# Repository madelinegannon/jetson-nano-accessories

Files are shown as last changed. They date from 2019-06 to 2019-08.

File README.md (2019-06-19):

### Jetson Nano Accessories
A variety of 3D printed mounts, adapters, and kits for NVIDIA's Jetson Nano.



## Overview

NVIDIA sent me a few of their new Jetson Nanos to play around and see what I might want to make. On first impression — the Nano is a solid Ubuntu computer, but I was really impressed with its portablity: if you look at their [Jetbot](https://github.com/NVIDIA-AI-IOT/jetbot) project, you can see that you can power the Nano plus a few motors with just a mobile phone charger. So that got me thinking about all the different — _and weird_ — places I could take a Nano ... and that led to me daydreaming about possible projects with this portable, powerful embedded computer.

To jumpstart my creativity, I decided to make a series of mounts, adapters, and kits for taking the Nano, a battery, and a camera into a bunch of different places. Some of them are pragmatic and useful — like the [Tripod Mount Kit](https://github.com/madelinegannon/jetson-nano-builds/blob/master/tripod-mount/). Others are a bit more odd and fun — like the [Utility Belt](https://github.com/madelinegannon/jetson-nano-builds/blob/master/utility-belt/) or [Gardening](https://github.com/madelinegannon/jetson-nano-builds/blob/master/gardening/) Kits.

I've included all the files to make and modify these 3D printable accessories in this repo. These kits let you attach the Nano to things like:
- Glass, with the [Suction Cup Kit](https://github.com/madelinegannon/jetson-nano-builds/blob/master/suction-cup-mount/)
- Metal, with the [Magnet Kit](https://github.com/madelinegannon/jetson-nano-builds/blob/master/magnetic-mount/)
- Tripods, with the [Tripod Kit](https://github.com/madelinegannon/jetson-nano-builds/blob/master/tripod-mount/)
- The Body, with the [Utility Belt Kit](https://github.com/madelinegannon/jetson-nano-builds/blob/master/utility-belt/)
- A Bike, with the [Bicycle Mount Kit](https://github.com/madelinegannon/jetson-nano-builds/blob/master/bicycle-mount/)
- The Ground, with the [Gardening Kit](https://github.com/madelinegannon/jetson-nano-builds/blob/master/gardening/)

| Suction Cup Kit | Magnet Kit | Tripod Kit | 
| :---: | :---: | :---: |
|  |   |  |

| Utility Belt | Bicycle Mount | Gardening Kit |
| :---: | :---: | :---: |
|  |  |  |

Plus I made a few stands for holding, displaying, or extending the Nano:

- [Nano Stand](https://github.com/madelinegannon/jetson-nano-builds/blob/master/stands/)
- [Nano Stand with Battery Clip](https://github.com/madelinegannon/jetson-nano-builds/blob/master/stands/)
- [Nano Stand with Battery Clip and Extruded Aluminium Extensions](https://github.com/madelinegannon/jetson-nano-builds/blob/master/stands/)

| Nano Stand | Nano Stand with Battery | Nano Stand with Battery and Extruded Aluminum |
| :---: | :---: | :---: |
|  |  |  | 

## Modular Clip System
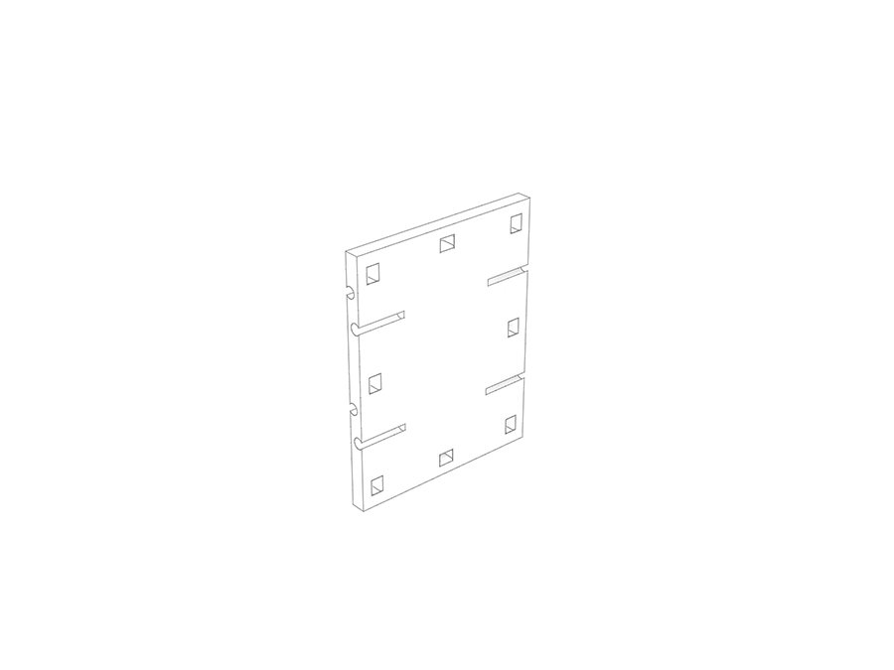
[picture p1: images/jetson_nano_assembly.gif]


My goal for these accessories was to have a kit of swapple, quick-to-print parts, so I could mix-and-match different clips, adapters, and mounts on the fly.

So, for example, over the course of my day, I could snap a Nano into the [Bicycle Mount Kit](https://github.com/madelinegannon/jetson-nano-builds/tree/master/bicycle-mount) for my commute to work, then snap it into a [Stand](https://github.com/madelinegannon/jetson-nano-builds/tree/master/stands) that's sitting on your workstation, and then maybe put my Nano on my [Refrigerator](https://github.com/madelinegannon/jetson-nano-builds/tree/master/magnetic-mount) or in my [Garden](https://github.com/madelinegannon/jetson-nano-builds/tree/master/garden-stake) when I got back home.  

### Components
The three basic components are a _Nano Clip_, that the Jetson Nano Developer Kit snaps into, a _Board Backer_, that protects the back of the Nano and has slots for the Nano and Battery Clips, and a _Battery Clip_, that a portable battery pack snaps into. Based on your scenario, you may or may need battery power — so there are other connection options for the rear slots in the Board Backer (e.g., [Suction Cups](https://github.com/madelinegannon/jetson-nano-builds/tree/master/suction-cup-mount)).

| Nano Clip | Board Backer | Battery Clip |
| :---: | :---: | :---: |
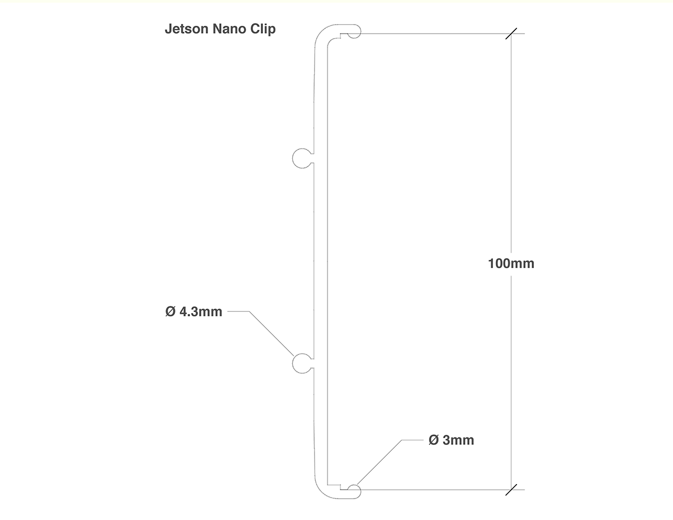
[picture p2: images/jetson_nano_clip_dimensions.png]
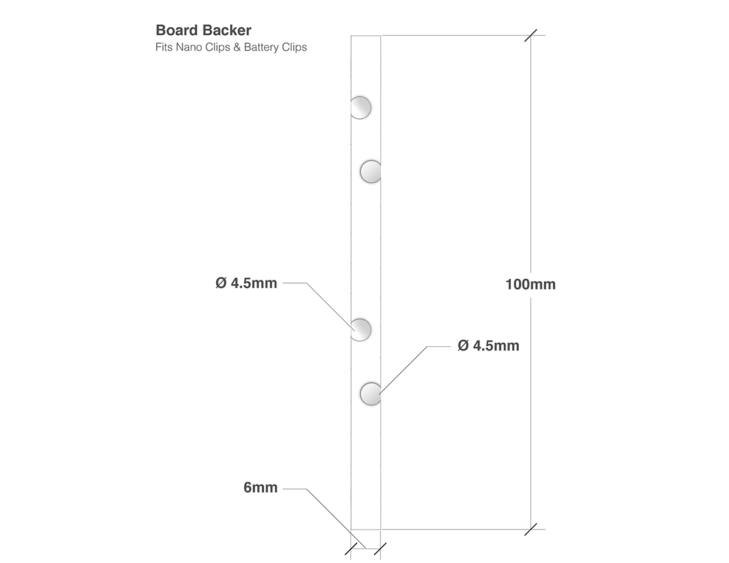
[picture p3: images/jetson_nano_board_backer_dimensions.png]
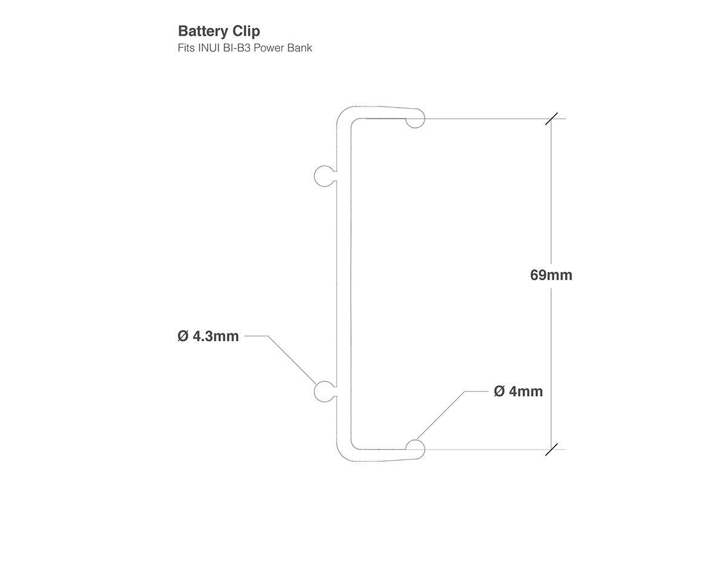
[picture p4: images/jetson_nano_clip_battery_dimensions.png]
|  |  |  |
| [jetson_nano_clip.stl](https://github.com/madelinegannon/jetson-nano-builds/blob/master/suction-cup-mount/jetson_nano_clip.stl) | [nano_board_backer.stl](https://github.com/madelinegannon/jetson-nano-builds/blob/master/suction-cup-mount/jetson_nano_board.stl) | [jetson_nano_clip_battery.stl](https://github.com/madelinegannon/jetson-nano-builds/blob/master/magnetic-mount/jetson_nano_clip_battery.stl) |

### Board Backer
The _Board Backer_ features slots for attaching the _Nano Clip_ and _Battery Clip_, as well as a series of holes for tip ties.

<p float="center">
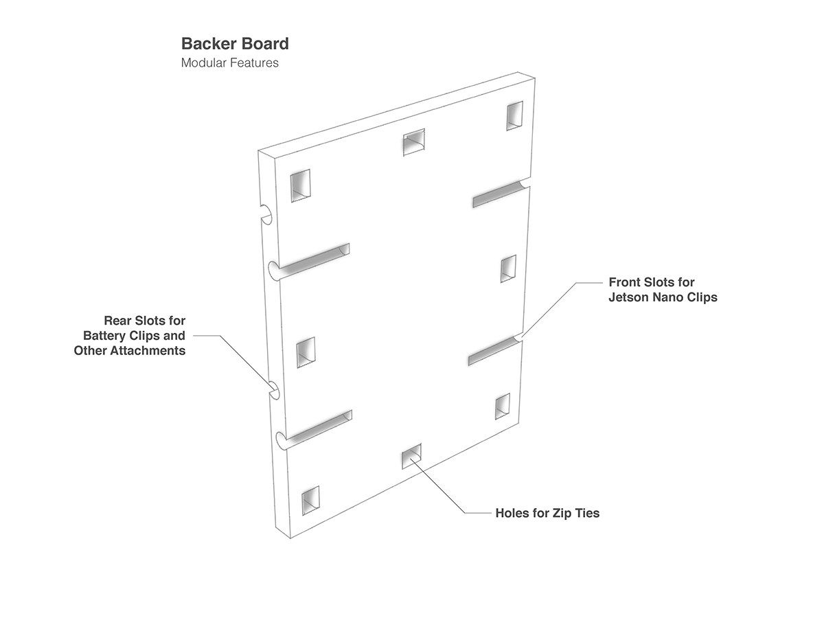
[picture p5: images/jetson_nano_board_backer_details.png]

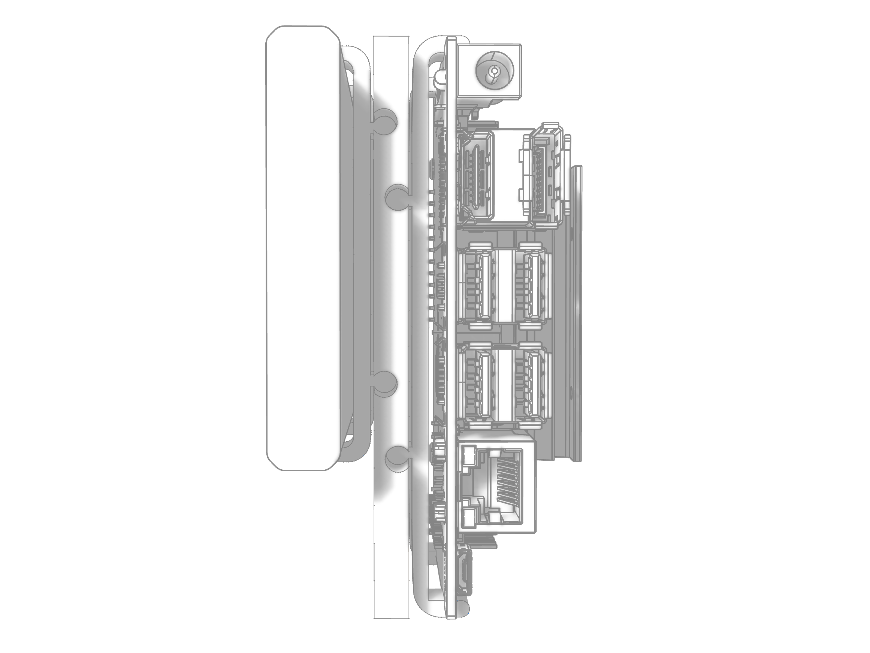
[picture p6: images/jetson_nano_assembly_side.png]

</p>

### Additional Clips
Here are a few more clips for the rear of the Board Backer that connect your Nano to different things:

| Bicycle Clips | Suction Cup Clips | Tripod Clips |
| :---: | :---: | :---: |
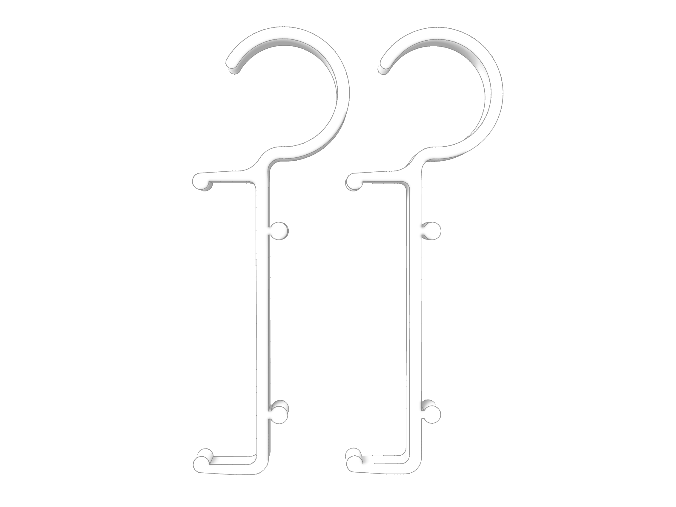
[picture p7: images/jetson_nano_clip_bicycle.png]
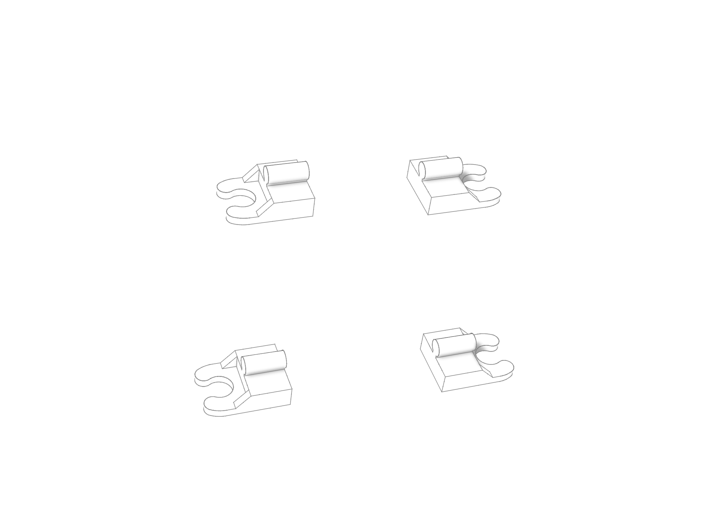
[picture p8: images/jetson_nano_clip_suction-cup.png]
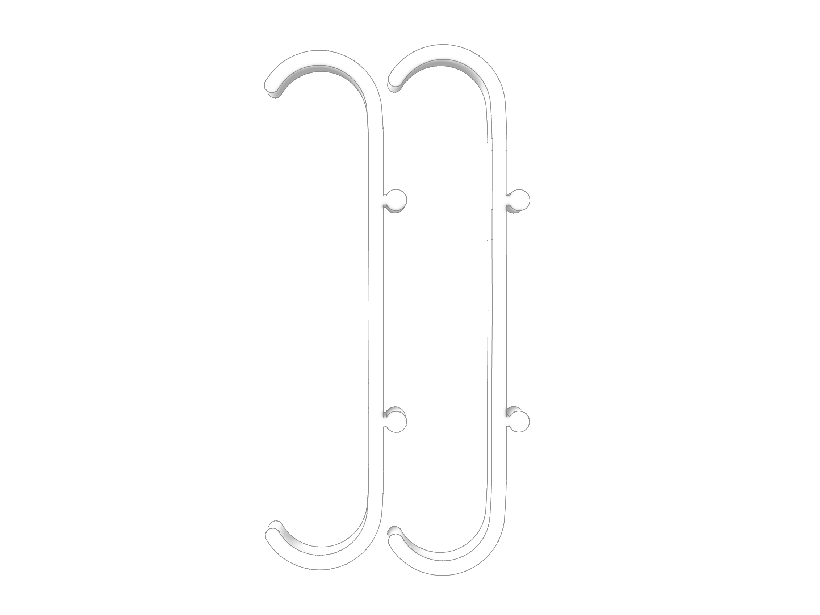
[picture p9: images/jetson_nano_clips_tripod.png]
|  |  |  |
| See the [Bicycle Mount Kit](https://github.com/madelinegannon/jetson-nano-builds/blob/master/bicycle-mount/) | See the [Suction Cup Kit](https://github.com/madelinegannon/jetson-nano-builds/blob/master/suction-cup-mount/) | See the [Tripod Mount Kit](https://github.com/madelinegannon/jetson-nano-builds/blob/master/tripod-mount/) |

### Stands
If you just want to show off your Nano in your workspace, I also made a few self-supporting stands that you can print.

| Jetson Nano Stand | Stand with Battery Clip | Stand with Battery Clip and Extruded Aluminium |
| :---: | :---: | :---: |
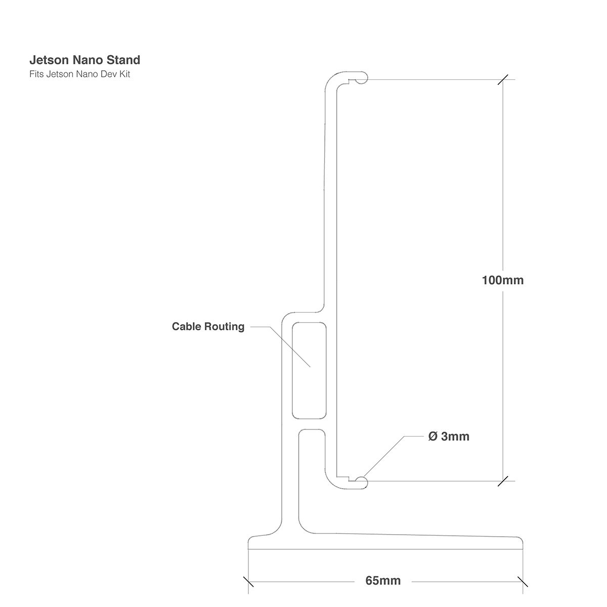
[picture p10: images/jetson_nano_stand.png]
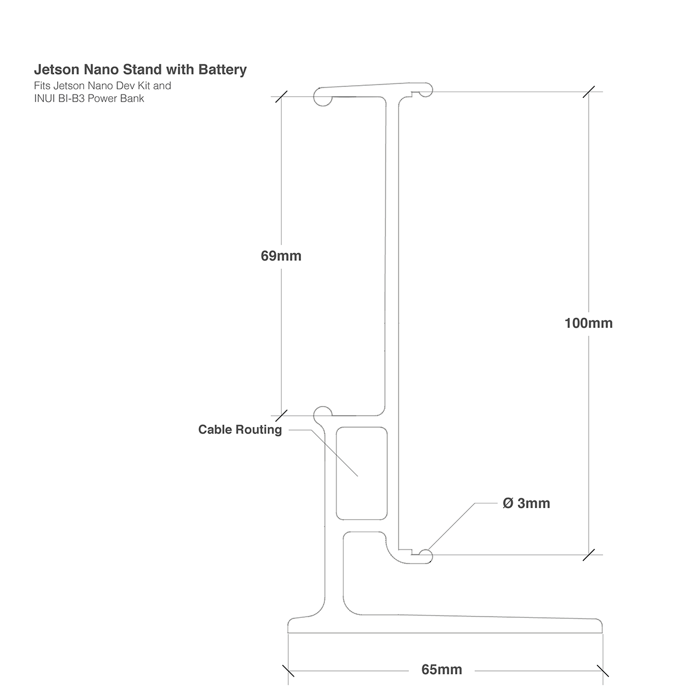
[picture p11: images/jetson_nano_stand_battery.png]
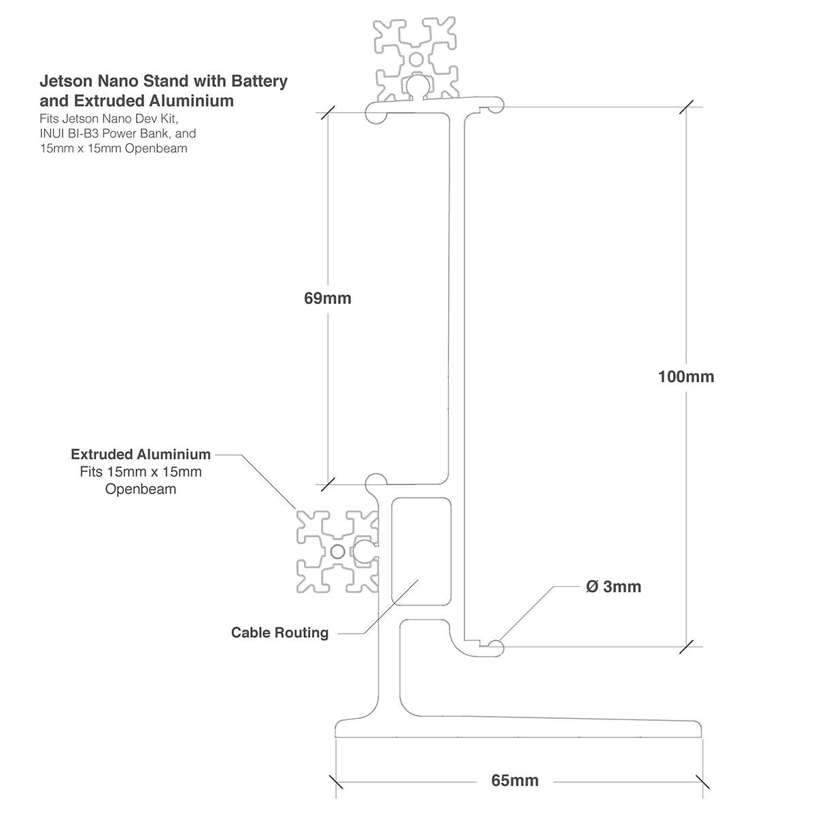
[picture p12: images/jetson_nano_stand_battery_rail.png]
|  |  |  |
| [jetson_nano_clip-feet.stl](https://github.com/madelinegannon/jetson-nano-builds/blob/master/stands/jetson_nano_clip-feet.stl) | [jetson_nano_clip-feet-battery.stl](https://github.com/madelinegannon/jetson-nano-builds/blob/master/stands/jetson_nano_clip-feet-battery.stl) | [jetson_nano_clip-feet-battery-rail.stl](https://github.com/madelinegannon/jetson-nano-builds/blob/master/stands/jetson_nano_clip-feet-battery-rail.stl) |

#### Build Settings
Each of included models were printed on a [Prusa i3 MK3S](https://www.prusa3d.com/original-prusa-i3-mk3/) printer. All my build settings are detail in the instructions for each assembly, but keep in mind that your settings and tolerances may vary based on the printer and printing method you use.

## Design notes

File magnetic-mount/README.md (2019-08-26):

### Jetson Nano Magnetic Mount

This Magnetic Mount Kit adds super-strong magnets to the back of your Jetson Nano, so you can stick it to metal surfaces that can be hard-to-reach or moving. 

|  Magnetic Mount (Overall) | Magnetic Mount (Detail) |
| :---: | :---: |
|  |  |

Here's a few project ideas to get started:
- Mount to your refrigerator, and use [real-time object detection](https://jkjung-avt.github.io/yolov3/) to keep track of groceries.
- Mount to your workbench, and use [real-time object detection](https://jkjung-avt.github.io/yolov3/) to keep track of where you put your tools.
- Mount to a structure, like an I-Beam, to detect who has been walking by.

> The neodymium magnets spec'ed here are quite strong, so be careful to not scratch the surface you're attaching to.

## Components

| Nano Clip | Battery Clip | Magnetic Board Backer | Magnet Clips |
| :---: | :---: | :---: | :---: |
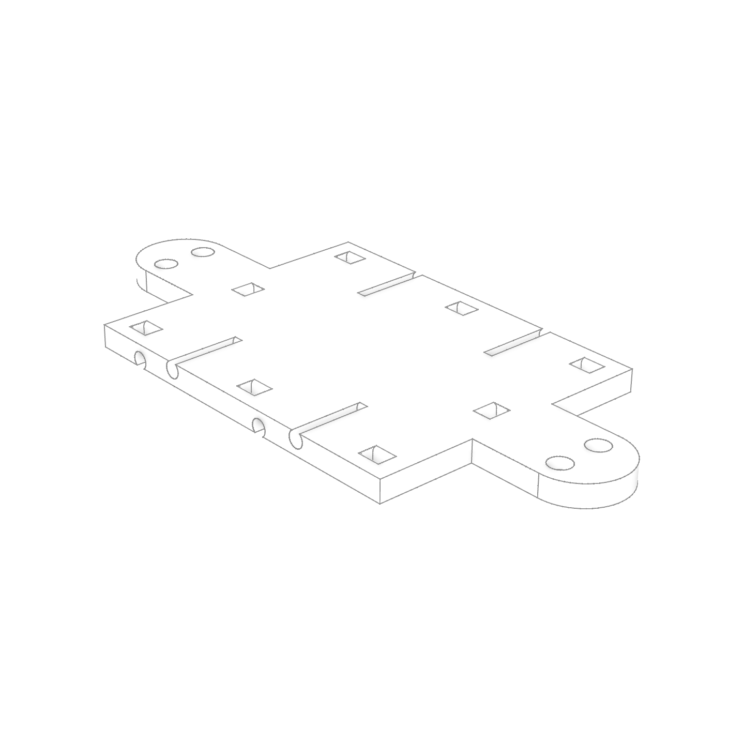
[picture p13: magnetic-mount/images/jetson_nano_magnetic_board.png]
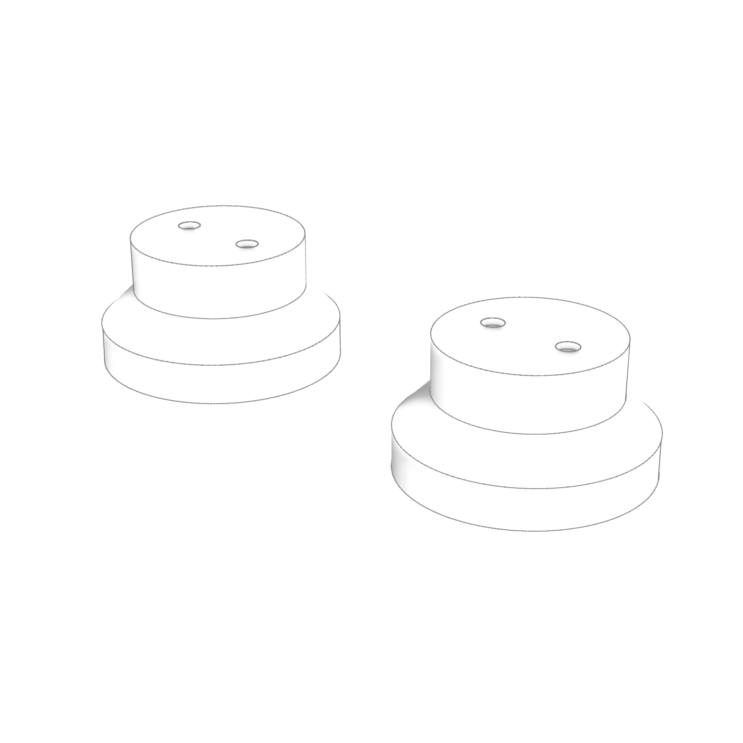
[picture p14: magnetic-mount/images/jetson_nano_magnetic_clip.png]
|  |  |  |  |

## Parts List

| Item | Qty | Reference  |
| --- |:---:| -----:|
| Magnetic Board Back | 1 | [jetson_nano_board_magnet.stl](https://github.com/madelinegannon/jetson-nano-builds/blob/master/magnetic-mount/jetson_nano_board_magnet.stl) |
| Magent Clip  | 2 | [jetson_nano_clip_magnet.stl](https://github.com/madelinegannon/jetson-nano-builds/blob/master/magnetic-mount/jetson_nano_clip_magnet.stl) |
| Nano Clip  | 2 | [jetson_nano_clip.stl](https://github.com/madelinegannon/jetson-nano-builds/blob/master/magnetic-mount/jetson_nano_clip.stl) |
| Battery Clip  | 2 | [jetson_nano_clip_battery.stl](https://github.com/madelinegannon/jetson-nano-builds/blob/master/magnetic-mount/jetson_nano_clip_battery.stl) |
| Neodymium Disc Magent | 2 | [32mm x 3mm Magnets](https://www.amazon.com/gp/product/B06XD2X45M/) |
| M3x8 screw | 2 | [Assorted Screw Set](https://www.amazon.com/VIGRUE-1080pcs-Assortment-Kit-Wrenches/dp/B07FCDL2SY/) |
| M3 nut | 2 | [Assorted Screw Set](https://www.amazon.com/VIGRUE-1080pcs-Assortment-Kit-Wrenches/dp/B07FCDL2SY/) |
| Portable Battery | 1 | [INUI Power Bank](https://www.amazon.com/INIU-Portable-External-Powerbank-Compatible/dp/B07H6LB4J4/) |

## Assembly Instructions

1. Print the [jetson_nano_board_magnet.stl](https://github.com/madelinegannon/jetson-nano-builds/blob/master/magnetic-mount/jetson_nano_board_magnet.stl),  two [jetson_nano_clip_magnet.stl](https://github.com/madelinegannon/jetson-nano-builds/blob/master/magnetic-mount/jetson_nano_clip_magnet.stl), two [jetson_nano_clip.stl](https://github.com/madelinegannon/jetson-nano-builds/blob/master/garden-stake/jetson_nano_clip.stl), and two [jetson_nano_clip_battery.stl](https://github.com/madelinegannon/jetson-nano-builds/blob/master/magnetic-mount/jetson_nano_clip_battery.stl) at 20% infill.
2. Attach the Magnet Clips to the printed boards.
    - Begin by pushing two M3 nuts into the hexagonal holes inside each of the Magent Clips.
    - Screw each of the Magent Clips to the back of the printed board using two M3x8 screws.
    - Push in a Disc Magent into the bottom of each Magnet Clip (this should be a tight fiction fit and snap into place).
        - The Magnet Clips _should_ hold each Disc Magnet in place with friction alone — add glue if the fit is too loose.
3. Slide the two Jetson Nano Clips into the front of the printed board (this should be a tight fiction fit). 
    - _Note: The front of the board has centered slots and a rougher finish._
4. Snap your Jetson Nano into the Clips — you should hear a nice click sound.
5. Slide the two Battery Clips into the back of the printed board (this should be a tight fiction fit). 
    - _Note: The back of the board has off-centered slots and a smoother finish._
6. Snap your Portable Battery into the Battery Clips, and plug in the Nano and other peripherals.
7. Stick onto a metal surface and go!

#### Printer Settings
Each of these parts were printed on a [Prusa i3 MK3S](https://www.prusa3d.com/original-prusa-i3-mk3/) printer using the MK3S_MK3_0.2_Fast profile (0.2mm layer height) with PLA. 

## Credits
1. The [Nano Clip](https://github.com/madelinegannon/jetson-nano-builds/blob/master/magnetic-mount/jetson_nano_clip.stl) and [Battery Clip](https://github.com/madelinegannon/jetson-nano-builds/blob/master/magnetic-mount/jetson_nano_clip_battery.stl) were derived from this [8020 Rail ATMega2560 Clip](https://www.thingiverse.com/thing:155130) by [the_digital_dentist](https://www.thingiverse.com/the_digital_dentist/about).

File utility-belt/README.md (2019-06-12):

### Jetson Nano Utility Belt
The Jetson Nano is lightweight and power-efficient, which means you can easily wear it on your body. This Utility Belt assembly places the Jetson Nano developer kit and a portable battery pack around your waist, so you can add cameras, sensors, and robots directly on your person.

|  Utility Belt (Overall) | Utility Belt (Detail) |
| :---: | :---: |
|  |  |

Here's a few project ideas to get started:
- Build your own DIY Head Mounted Device.
- Make robotic garments that respond to their environment.
- Create a "sixth sense" that lets to navigate the world in a new way.
- Make a sassy robotic parrot that lives on your shoulder.

> Keep in mind that the Nano's heat sink can get hot, and that the board can short if it comes into contact with metal (like from watches or bracelets). Consider adding a case around the top of the board if how you wear your is likely to come in contact with skin or metal. 

## Components

| Nano Clip | Belt Board Buckle | Belt Battery Buckle |
| :---: | :---: | :---: |
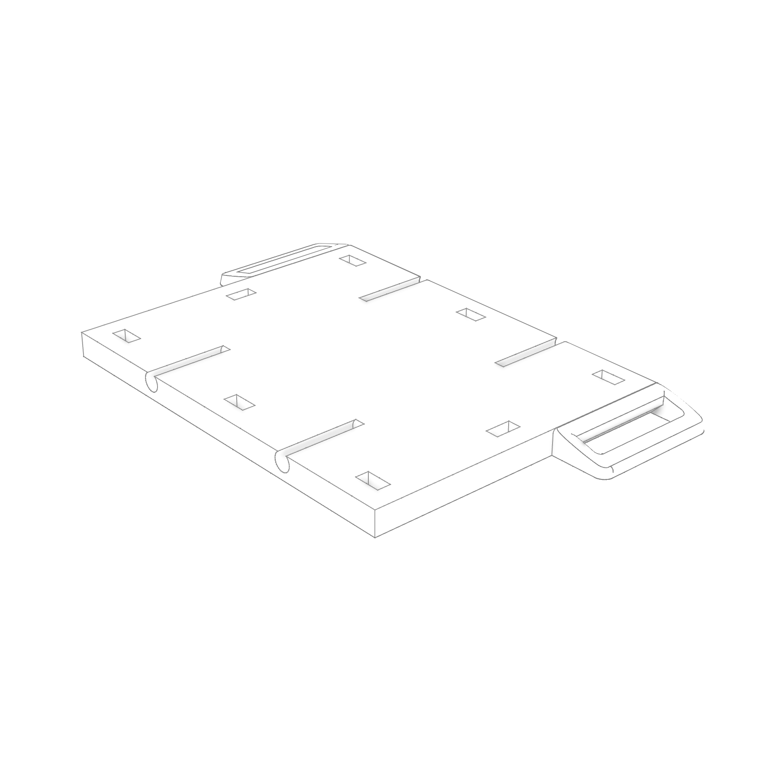
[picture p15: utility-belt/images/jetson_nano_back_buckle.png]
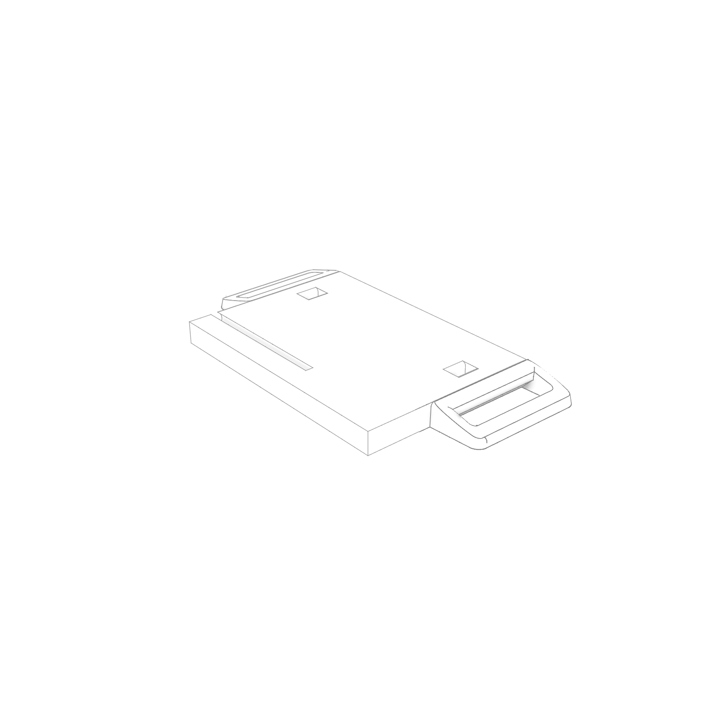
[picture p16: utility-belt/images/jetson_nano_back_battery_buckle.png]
|  |  |  | 

## Parts List

| Item | Qty | Reference  |
| --- |:---:| -----:|
| Nano Board Buckle | 1 | [jetson_nano_board_buckle.stl](https://github.com/madelinegannon/jetson-nano-builds/blob/master/utility-belt/jetson_nano_board_buckle.stl) |
| Battery Board Buckle | 1 | [jetson_nano_battery_buckle.stl](https://github.com/madelinegannon/jetson-nano-builds/blob/master/utility-belt/jetson_nano_battery_buckle.stl) |
| Nano Clip  | 2 | [jetson_nano_clip.stl](https://github.com/madelinegannon/jetson-nano-builds/blob/master/garden-utility/jetson_nano_clip.stl) |
| Battery Clip (Vertical) | 1 | [jetson_nano_clip_battery-vertical.stl](https://github.com/madelinegannon/jetson-nano-builds/blob/master/utility-belt/jetson_nano_clip_battery-vertical.stl) |
| Buckles, Glides, & Nylon Strap | — | [BTNOW 15 Piece Set](https://www.amazon.com/gp/product/B075ZTLKJC/) |
| Portable Battery | 1 | [INUI Power Bank](https://www.amazon.com/INIU-Portable-External-Powerbank-Compatible/dp/B07H6LB4J4/) |

## Assembly Instructions

1. Print the [jetson_nano_board_buckle.stl](https://github.com/madelinegannon/jetson-nano-builds/blob/master/utility-belt/jetson_nano_board_buckle.stl), [jetson_nano_battery_buckle.stl](https://github.com/madelinegannon/jetson-nano-builds/blob/master/utility-belt/jetson_nano_battery_buckle.stl), two [jetson_nano_clip.stl](https://github.com/madelinegannon/jetson-nano-builds/blob/master/garden-utility/jetson_nano_clip.stl), and one [jetson_nano_clip_battery-vertical.stl](https://github.com/madelinegannon/jetson-nano-builds/blob/master/utility-belt/jetson_nano_clip_battery-vertical.stl) at 20% infill.
2. Slide the two Jetson Nano Clips into the front of the printed board with buckle (this should be a tight fiction fit). 
    - _Note: This board has multiple slots for clips._
3. Snap your Jetson Nano into the Clips — you should hear a nice click sound.
4. Slide the one Battery Clip (Vertical) into the back of the printed battery board with buckle (this should be a tight fiction fit). 
    - _Note: The battery board only has one slot for a clip._
5. Snap your Portable Battery into the Battery Clip, and plug in the Nano and other peripherals.
6. Attach the plastic Buckle, Glides, and Nylon Straps following these instructions: [Steps 1-6](https://images-na.ssl-images-amazon.com/images/I/91%2BgqnHoY0L._SL1500_.jpg) and [Steps 7-10](https://images-na.ssl-images-amazon.com/images/I/81tcsMIyBYL._SL1500_.jpg).
7. Adjust the Nano and Portable Battery so that the weight is balanced.
8. Buckle up and go.

#### Printer Settings
Each of these parts were printed on a [Prusa i3 MK3S](https://www.prusa3d.com/original-prusa-i3-mk3/) printer using the MK3S_MK3_0.2_Fast profile (0.2mm layer height) with PLA. 

## Credits
1. The [Nano Clip](https://github.com/madelinegannon/jetson-nano-builds/blob/master/garden-utility/jetson_nano_clip.stl) and [Battery Clip](https://github.com/madelinegannon/jetson-nano-builds/blob/master/garden-utility/jetson_nano_clip_battery-vertical.stl) were derived from this [8020 Rail ATMega2560 Clip](https://www.thingiverse.com/thing:155130) by [the_digital_dentist](https://www.thingiverse.com/the_digital_dentist/about).

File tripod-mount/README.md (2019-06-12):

### Jetson Nano Tripod Mount
This Jetson Nano Tripod Mount lets you attach the Jetson Nano developer kit to any leg of a [Manfrotto 028B Tripod](https://www.manfrotto.us/black-triman-camera-tripod). Attaching the Nano to the tripod leg keeps the tripod head clear for cameras and other sensors, while keeping the computer close and mobile. This design takes advantage of the 028B's tapered, twin shanked leg — so you can easily snap on the printed tripod clips, and slide the assembly up the leg until you have a snug connection.

|  Tripod Mount (Overall) | Tripod Mount (Detail) |
| :---: | :---: |
|  |  |

## Components

| Nano Clip | Board Backer | Tripod Clips |
| :---: | :---: | :---: |
|  |  |  |

## Parts List

| Item | Qty | Reference  |
| --- |:---:| -----:|
| Board Back | 1 | [jetson_nano_board.stl](https://github.com/madelinegannon/jetson-nano-builds/blob/master/tripod-mount/jetson_nano_board.stl) |
| Nano Clip  | 2 | [jetson_nano_clip.stl](https://github.com/madelinegannon/jetson-nano-builds/blob/master/tripod-mount/jetson_nano_clip.stl) |
| Nano Tripod Clips | 1 | [jetson_nano_clips_tripod.stl](https://github.com/madelinegannon/jetson-nano-builds/blob/master/tripod-mount/jetson_nano_clips_tripod.stl) |

## Assembly Instructions

1. Print the [jetson_nano_board.stl](https://github.com/madelinegannon/jetson-nano-builds/blob/master/tripod-mount/jetson_nano_board.stl),  [jetson_nano_clips_tripod.stl](https://github.com/madelinegannon/jetson-nano-builds/blob/master/tripod-mount/jetson_nano_clips_tripod.stl), and two [jetson_nano_clip.stl](https://github.com/madelinegannon/jetson-nano-builds/blob/master/garden-utility/jetson_nano_clip.stl) at 20% infill.
2. Slide the two Jetson Nano Clips into the front of the printed board (this should be a tight fiction fit). 
    - _Note: The front of the board has centered slots and a rougher finish._
3. Snap your Jetson Nano into the Clips — you should hear a nice click sound.
4. Slide the two Tripod Clips into the back of the printed board (this should be a tight fiction fit). 
    - The two Tripod Clips are slightly different widths to account for the taper of the tripod leg.
        - The wider clip goes in the top slot on the back of the board.
        - The narrower clip goes in the bottom slot on the back of the board.
    -  _Note: The back of the board has off-centered slots and a smoother finish._
5. Once the tripod clips are attached, position the clips over the middle of the leg, and then slide the assembly up the leg until you feel a snug fit. This should be around 2"- 3" from the top of the leg.
6. Plug in power, sensors and peripherals, and get going.

#### Printer Settings
Each of these parts were printed on a [Prusa i3 MK3S](https://www.prusa3d.com/original-prusa-i3-mk3/) printer using the MK3S_MK3_0.2_Fast profile (0.2mm layer height) with PLA. 

## Credits
1. The [Nano Clip](https://github.com/madelinegannon/jetson-nano-builds/blob/master/garden-utility/jetson_nano_clip.stl) was derived from this [8020 Rail ATMega2560 Clip](https://www.thingiverse.com/thing:155130) by [the_digital_dentist](https://www.thingiverse.com/the_digital_dentist/about).

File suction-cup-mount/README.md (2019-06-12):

### Jetson Nano Suction Cup Mount
This Suction Cup Mount Kit adds suction cups to the back of your Jetson Nano, so you can stick it in hard-to-reach or moving surfaces. The suction cups work best on clean, smooth surfaces, such as glass or acrylic.

|  Suction Cup Mount (Overall) | Suction Cup Mount (Detail) |
| :---: | :---: |
|  |  |

Here's a few project ideas to get started:
- Mount inside your car, and use the Nano to create a DIY head's up display
- Mount to a window, and use the Nano as a motion detector
- Mount to a dry-erase board, and use the Nano for real-time sketch recognition

## Components

| Nano Clip | Board Backer | Suction Cup Clips |
| :---: | :---: | :---: |
|  |  |  |
| [jetson_nano_clip.stl](https://github.com/madelinegannon/jetson-nano-builds/blob/master/suction-cup-mount/jetson_nano_clip.stl) | [nano_board_backer.stl](https://github.com/madelinegannon/jetson-nano-builds/blob/master/suction-cup-mount/jetson_nano_board.stl) | [jetson_nano_clips_suction-cup.stl](https://github.com/madelinegannon/jetson-nano-builds/blob/master/suction-cup-mount/jetson_nano_clip_suction-cup.stl) |

## Parts List

| Item | Qty | Reference  |
| --- |:---:| -----:|
| Board Back | 1 | [jetson_nano_board.stl](https://github.com/madelinegannon/jetson-nano-builds/blob/master/suction-cup-mount/jetson_nano_board.stl) |
| Nano Clip  | 2 | [jetson_nano_clip.stl](https://github.com/madelinegannon/jetson-nano-builds/blob/master/suction-cup-mount/jetson_nano_clip.stl) |
| Suction Cup Clip | 4 | [jetson_nano_clips_suction-cup.stl](https://github.com/madelinegannon/jetson-nano-builds/blob/master/suction-cup-mount/jetson_nano_clip_suction-cup.stl) |
| 30mm Suction Cups | 4 | [Assorted Suction Cups](https://www.amazon.com/gp/product/B07H6CTWL4/) |

## Assembly Instructions

1. Print the [jetson_nano_board.stl](https://github.com/madelinegannon/jetson-nano-builds/blob/master/suction-cup-mount/jetson_nano_board.stl), two [jetson_nano_clip.stl](https://github.com/madelinegannon/jetson-nano-builds/blob/master/suction-cup-mount/jetson_nano_clip.stl), and four [jetson_nano_clips_tripod.stl]([jetson_nano_clips_suction-cup.stl](https://github.com/madelinegannon/jetson-nano-builds/blob/master/suction-cup-mount/jetson_nano_clip_suction-cup.stl) at 20% infill.
2. Slide the two Jetson Nano Clips into the front of the printed board (this should be a tight fiction fit). 
    - _Note: The front of the board has centered slots and a rougher finish._
3. Snap your Jetson Nano into the Clips — you should hear a nice click sound.
4. Slide a 30mm suction cup into each of the Suction Cup Clips (this should be a tight fiction fit). 
5. Slide each of the Suction Cup Clips into the back of the printed board (this should be a tight fiction fit). 
    - _Note: The back of the board has off-centered slots and a smoother finish._
6. Thoroughly clean the surface you'll be suctioning to, and then give the assembly a good press down onto the surface.
   - These suction cups work best on completely smooth surfaces, such as glass. 
7. Stick it and go!

#### Printer Settings
Each of these parts were printed on a [Prusa i3 MK3S](https://www.prusa3d.com/original-prusa-i3-mk3/) printer using the MK3S_MK3_0.2_Fast profile (0.2mm layer height) with PLA. 

## Credits
1. The [Nano Clip](https://github.com/madelinegannon/jetson-nano-builds/blob/master/garden-utility/jetson_nano_clip.stl) was derived from this [8020 Rail ATMega2560 Clip](https://www.thingiverse.com/thing:155130) by [the_digital_dentist](https://www.thingiverse.com/the_digital_dentist/about).

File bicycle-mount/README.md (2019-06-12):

### Jetson Nano Bicycle Mount
The Jetson Nano is lightweight and power-efficient, which means you can easily take it on the go. This Bicycle Mount assembly allows you to hang a Jetson Nano Developer Kit and Portable Battery from the horizontal crossbar of your bike. It also lets you attach sensors, cameras, or projectors to your handlebars using a standard 1/4-20 screw. Combine the two, and you'll have a number of ways to creatively enhance your daily commute.

|  Bicycle Mount (Overall) | Bicycle Mount (Detail) |
| :---: | :---: |
|  |  |

Here's a few project ideas to get started:
- Detect potholes and other hazards at night using an IR camera.
- Change the colors of LED lights on your bike based on proximity.
- Create a 3D map of your commute using a depth camera, like the [ZED](https://www.stereolabs.com/zed/) _(shown above)_.
- Attach a pico projector to add dynamic visuals to your night ride.

> The Jetson Nano is not waterproof, so use on a sunny day :)

## Components

| Nano Clip | Board Back | Bicycle Clips | Sensor Clip |
| :---: | :---: | :---: | :---: |
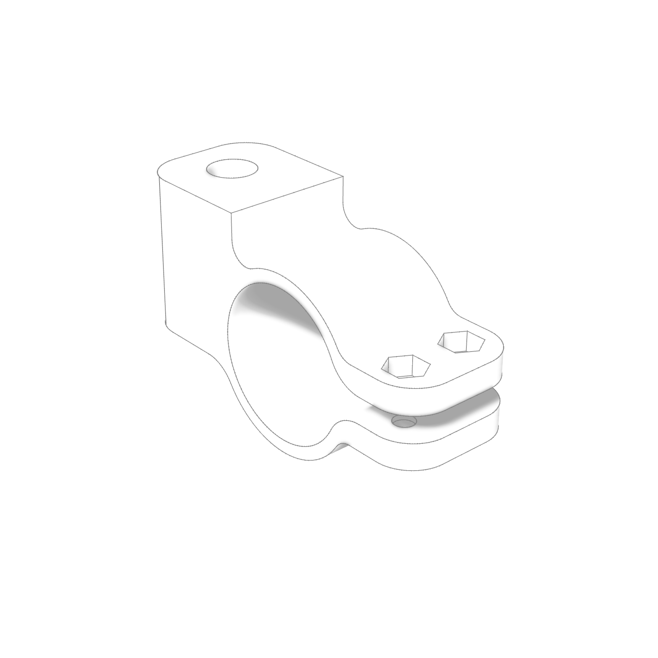
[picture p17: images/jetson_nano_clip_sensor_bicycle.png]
|  |  |  |  |

## Parts List

| Item | Qty | Reference  |
| --- |:---:| -----:|
| Board Back | 1 | [jetson_nano_board.stl](https://github.com/madelinegannon/jetson-nano-builds/blob/master/bicycle-mount/jetson_nano_board.stl) |
| Nano Clip  | 2 | [jetson_nano_clip.stl](https://github.com/madelinegannon/jetson-nano-builds/blob/master/bicycle-mount/jetson_nano_clip.stl) |
| Bicycle Clip | 2 | [jetson_nano_clip_bicycle.stl](https://github.com/madelinegannon/jetson-nano-builds/blob/master/bicycle-mount/jetson_nano_clip_bicycle.stl) |
| Bicycle Sensor Clip | 1 | [jetson_nano_clip_bicycle_sensor.stl](https://github.com/madelinegannon/jetson-nano-builds/blob/master/bicycle-mount/jetson_nano_clip_bicycle_sensor.stl) |
| M3x8 screw | 2 | [Assorted Screw Set](https://www.amazon.com/VIGRUE-1080pcs-Assortment-Kit-Wrenches/dp/B07FCDL2SY/) |
| M3 nut | 2 | [Assorted Screw Set](https://www.amazon.com/VIGRUE-1080pcs-Assortment-Kit-Wrenches/dp/B07FCDL2SY/) |
| 1/4-20 x 1" screw | 1 | [1/4-20 Screw Assortment](https://www.amazon.com/iExcell-4-20UNC-Stainless-Internal-Drives/dp/B07C9MWCSP/) |
| Portable Battery | 1 | [INUI Power Bank](https://www.amazon.com/INIU-Portable-External-Powerbank-Compatible/dp/B07H6LB4J4/) |

## Assembly Instructions

1. Print the [jetson_nano_board.stl](https://github.com/madelinegannon/jetson-nano-builds/blob/master/tripod-mount/jetson_nano_board.stl), two [jetson_nano_clip.stl](https://github.com/madelinegannon/jetson-nano-builds/blob/master/garden-utility/jetson_nano_clip.stl), and two [jetson_nano_clip_bicycle.stl](https://github.com/madelinegannon/jetson-nano-builds/blob/master/car-mount/jetson_nano_bicycle.stl) at 20% infill. Print one [jetson_nano_clip_bicycle_sensor.stl](https://github.com/madelinegannon/jetson-nano-builds/blob/master/car-mount/jetson_nano_bicycle_sensor.stl) at 10% infill.
2. Slide the two Jetson Nano Clips into the front of the printed board (this should be a tight fiction fit). 
    - _Note: The front of the board has centered slots and a rougher finish._
3. Snap your Jetson Nano into the Clips — you should hear a nice click sound.
4. Slide each of the Bicylce Clips into the back of the printed board (this should be a tight fiction fit). 
    - _Note: The back of the board has off-centered slots and a smoother finish._
5. Snap your Portable Battery into the back of the Bicycle Clips, and plug in the Nano and other peripherals.
6. Use the hooks of the bicycle clips to hang the whole assembly from the horizontal crossbar of your bike.
    - The hooks were designed for a 1" diameter crossbar.
    - If you find your Nano assembly is sliding forwards and backwards, add a zip tie before the first clip and after the last clip on your crossbar — these zip ties will act as stoppers. 
7. Snap the bicycle Sensor Clip around a handlebar of your bike.
    - Push the clip around the handlebar, with the hexagonal holes facing up and towards the bike seat. It should take some force to it on; but once on, the clip should be slightly loose around the handle bars.
    - The intrerior diameter of the Sensor Clip is just under 1" (23mm). However, the clips will fit larger diameter handlebars — you'll just need longer M3 screws.
8. Push two M3 nuts into the hexagonal holes on the Sensor Clip (these should be a tight fiction fit).
9. Screw two M3x8 screws from the bottom of the clip, through the M3 nuts. Tighten the two screws until the clip no longer slides or rotates.
10. Use the 1/4-20 x 1" screw to attach any number of sensors, cameras, or projectors to your handlebars.
11. Start pedalling and go!

#### Printer Settings
Each of these parts were printed on a [Prusa i3 MK3S](https://www.prusa3d.com/original-prusa-i3-mk3/) printer using the MK3S_MK3_0.2_Fast profile (0.2mm layer height) with PLA. 

## Credits
1. The [Nano Clip](https://github.com/madelinegannon/jetson-nano-builds/blob/master/garden-utility/jetson_nano_clip.stl) was derived from this [8020 Rail ATMega2560 Clip](https://www.thingiverse.com/thing:155130) by [the_digital_dentist](https://www.thingiverse.com/the_digital_dentist/about).

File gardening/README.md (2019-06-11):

### Jetson Nano Garden Stake
The Jetson Nano is lightweight and power-efficient, which means you can easily take it outdoors. This Garden Stake assembly has a place to clip in a Jetson Nano developer kit and a portable battery pack, as well as cameras and other peripherals. The pointy stake is great for holding the Nano in soft ground.

Here's a few project ideas to get started:
- Detect and report on bugs and pests in your garden.
- Detect poorly irrigated parts of your lawn.
- Take it to the beach to monitor your sun exposure.
- Use it to drive your outdoor projection mapping projects.

> The Jetson Nano is not waterproof, so use on a sunny day :)



## Components

| Nano Clip | Battery Clip | Outdoor Board Back | Stake |
| :---: | :---: | :---: | :---: |
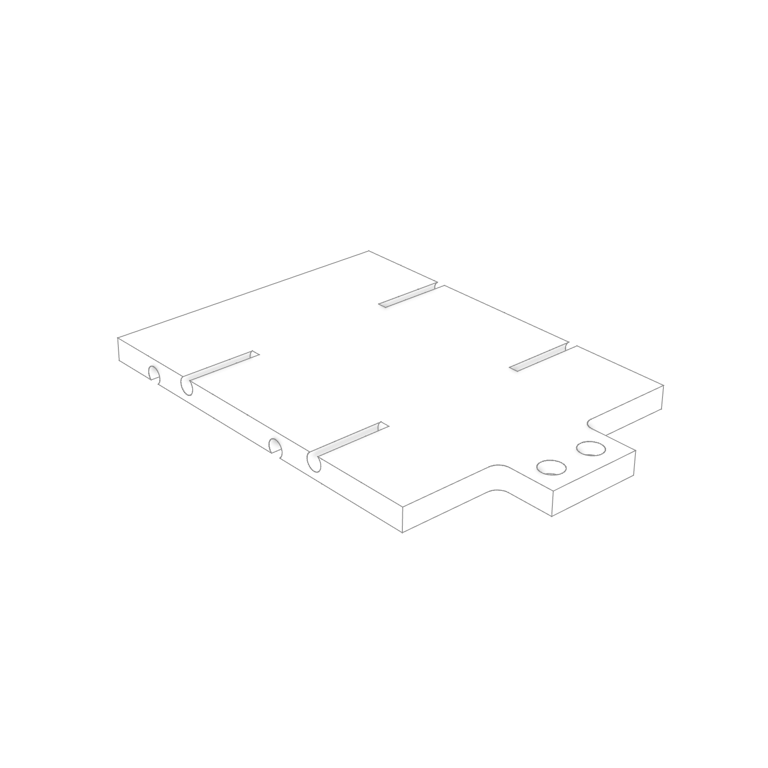
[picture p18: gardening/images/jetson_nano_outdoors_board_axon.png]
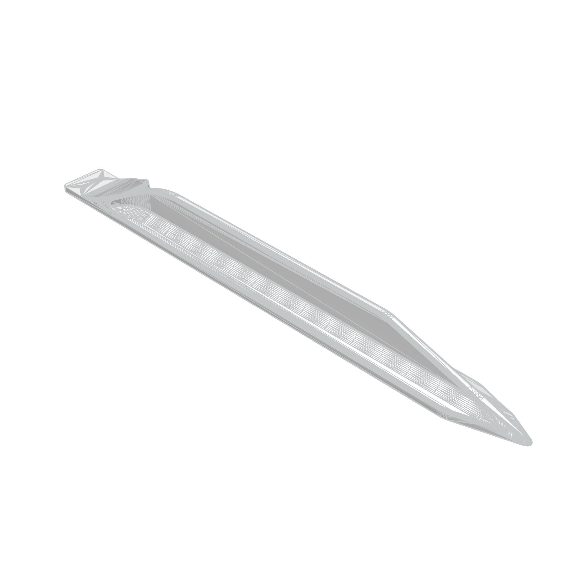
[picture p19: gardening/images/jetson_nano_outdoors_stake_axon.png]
|  |  |  |  |

## Parts List

| Item | Qty | Reference  |
| --- |:---:| -----:|
| Stake | 1 | [jetson_nano_outdoors_stake.stl](https://github.com/madelinegannon/jetson-nano-builds/blob/master/gardening/jetson_nano_outdoors_stake.stl) |
| Board Back | 1 | [jetson_nano_outdoors_stake_board.stl](https://github.com/madelinegannon/jetson-nano-builds/blob/master/gardening/jetson_nano_outdoors_stake_board.stl) |
| Nano Clip  | 2 | [jetson_nano_clip.stl](https://github.com/madelinegannon/jetson-nano-builds/blob/master/gardening/jetson_nano_clip.stl) |
| Battery Clip  | 2 | [jetson_nano_clip_battery.stl](https://github.com/madelinegannon/jetson-nano-builds/blob/master/gardening/jetson_nano_clip_battery.stl) |
| M3x12 screw | 2 | [Assorted Screw Set](https://www.amazon.com/VIGRUE-1080pcs-Assortment-Kit-Wrenches/dp/B07FCDL2SY/) |
| M3 nut | 2 | [Assorted Screw Set](https://www.amazon.com/VIGRUE-1080pcs-Assortment-Kit-Wrenches/dp/B07FCDL2SY/) |
| Portable Battery | 1 | [INUI Power Bank](https://www.amazon.com/INIU-Portable-External-Powerbank-Compatible/dp/B07H6LB4J4/) |

## Assembly Instructions

1. Print the [jetson_nano_outdoors_stake.stl](https://github.com/madelinegannon/jetson-nano-builds/blob/master/gardening/jetson_nano_outdoors_stake.stl) at 10% infill.
2. Print the [jetson_nano_outdoors_stake_board.stl](https://github.com/madelinegannon/jetson-nano-builds/blob/master/gardening/jetson_nano_outdoors_stake_board.stl) and two [jetson_nano_clip.stl](https://github.com/madelinegannon/jetson-nano-builds/blob/master/gardening/jetson_nano_clip.stl) at 20% infill.
3. Slide the two Jetson Nano Clips into the front of the printed board (this should be a tight fiction fit). 
    - _Note: The front of the board has centered slots and a rougher finish._
4. Snap your Jetson Nano into the Clips — you should hear a nice click sound.
5. Slide the two Battery Clips into the back of the printed board (this should be a tight fiction fit). 
    - _Note: The back of the board has off-centered slots and a smoother finish._
6. Snap your Portable Battery into the Battery Clips, and plug in the Nano and other peripherals.
7. Bolt the board to the stake using the M3 screws and washers.
8. Stick into the ground and go!

#### Printer Settings
Each of these parts were printed on a [Prusa i3 MK3S](https://www.prusa3d.com/original-prusa-i3-mk3/) printer using the MK3S_MK3_0.2_Fast profile (0.2mm layer height) with PLA. 

## Credits
1. The [Stake](https://github.com/madelinegannon/jetson-nano-builds/blob/master/gardening/jetson_nano_outdoors_stake_board.stl) was moded from this [Tent Stake](https://www.thingiverse.com/thing:2758339) by [mistertech](https://www.thingiverse.com/mistertech/about).
2. The [Nano Clip](https://github.com/madelinegannon/jetson-nano-builds/blob/master/gardening/jetson_nano_clip.stl) and [Battery Clip](https://github.com/madelinegannon/jetson-nano-builds/blob/master/gardening/jetson_nano_clip_battery.stl) were derived from this [8020 Rail ATMega2560 Clip](https://www.thingiverse.com/thing:155130) by [the_digital_dentist](https://www.thingiverse.com/the_digital_dentist/about).

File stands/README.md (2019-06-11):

### Jetson Nano Stands
Display and extend your Nano with these different stands.

## Nano Stand
This stand holds your Nano vertically off your worksurface, and has some space for neatly routing cables.

| Stand (Side) | Stand (Image) |
| :---: | :---: |
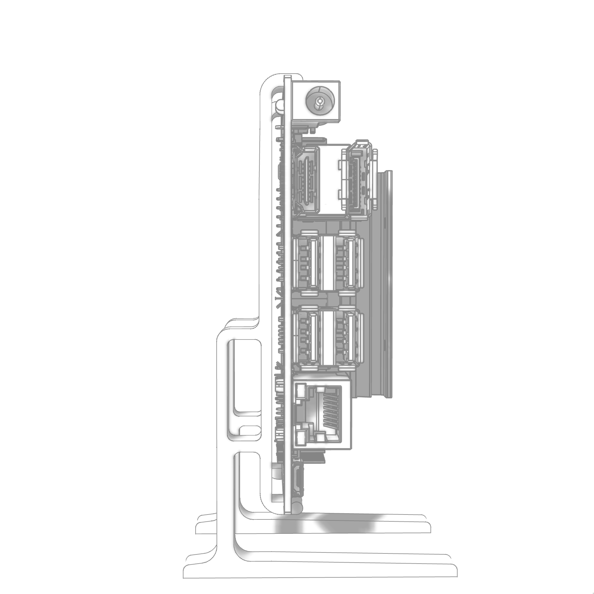
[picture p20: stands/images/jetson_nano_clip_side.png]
|  |  |

##  Nano Stand with Battery Clip
This stand integrates a clip to hold a portable battery, in case your power source is too far away.

|  Stand with Battery (Side) | Stand with Battery (Axon) |
| :---: | :---: |
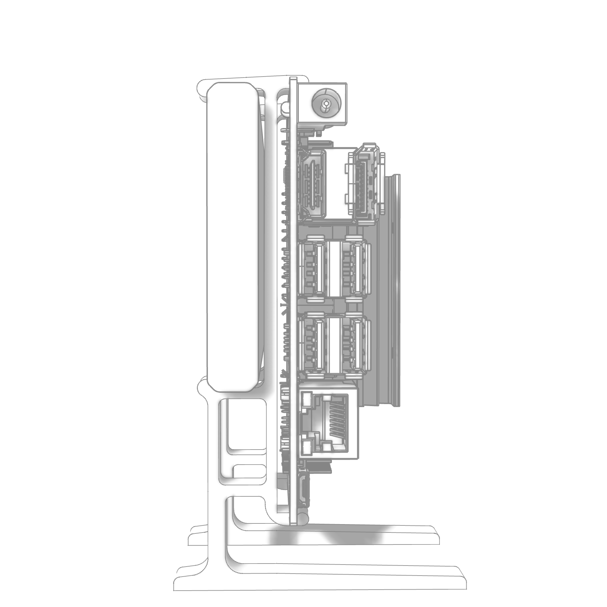
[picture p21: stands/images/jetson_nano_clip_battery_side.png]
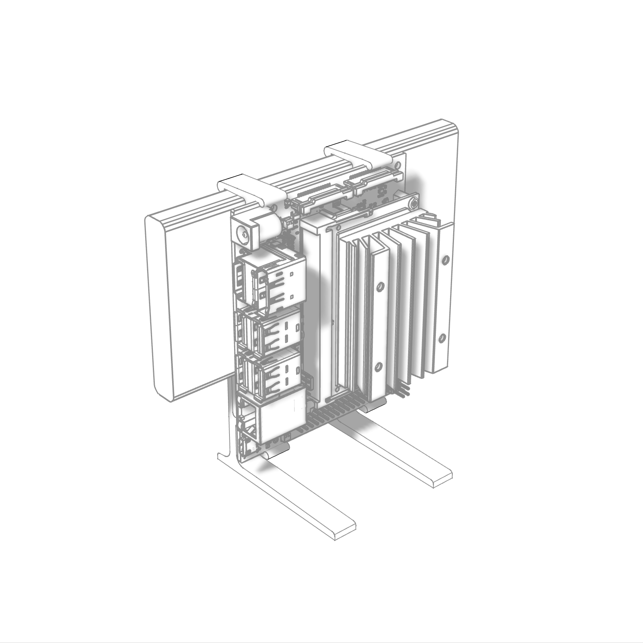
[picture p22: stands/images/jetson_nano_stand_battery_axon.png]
|  |  |

##  Nano Stand with Battery Clip and Extruded Aluminium Extensions
This stand add a few nodes for attaching 15mm x 15mm extruded aluminium rails. This lets you more easily create a custom rig for your Nano — for example, like this custom Sketch Recognition rig:

|  Stand with Battery and Rail (Side) | Stand with Battery and Rail (Image) |
| :---: | :---: |
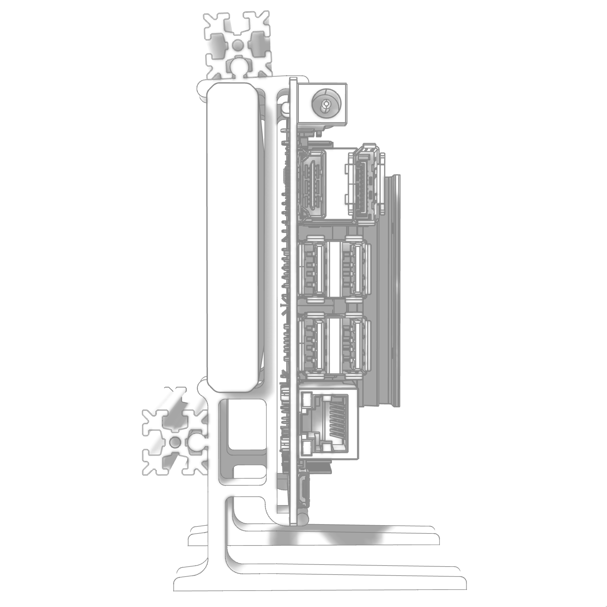
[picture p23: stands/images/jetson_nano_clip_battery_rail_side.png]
|  |  |

## Components

| Jetson Nano Stand | Stand with Battery Clip | Stand with Battery Clip and Extruded Aluminium |
| :---: | :---: | :---: |
|  |  |  |
| [jetson_nano_clip-feet.stl](https://github.com/madelinegannon/jetson-nano-builds/blob/master/stands/jetson_nano_clip-feet.stl) | [jetson_nano_clip-feet-battery.stl](https://github.com/madelinegannon/jetson-nano-builds/blob/master/stands/jetson_nano_clip-feet-battery.stl) | [jetson_nano_clip-feet-battery-rail.stl](https://github.com/madelinegannon/jetson-nano-builds/blob/master/stands/jetson_nano_clip-feet-battery-rail.stl) |

## Parts List

| Item | Qty | Reference  |
| --- |:---:| -----:|
| Nano Stand | 2 | [jetson_nano_clip-feet.stl](https://github.com/madelinegannon/jetson-nano-builds/blob/master/stands/jetson_nano_clip-feet.stl) |
| Nano Stand with Battery Clip  | 2 | [jetson_nano_clip-feet-battery.stl](https://github.com/madelinegannon/jetson-nano-builds/blob/master/stands/jetson_nano_clip-feet-battery.stl) |
| Nano Stand with Battery Clip and Extruded Aluminium Extensions | 2 | [jetson_nano_clip-feet-battery-rail.stl](https://github.com/madelinegannon/jetson-nano-builds/blob/master/stands/jetson_nano_clip-feet-battery-rail.stl) |
| Portable Battery | 1 | [INUI Power Bank](https://www.amazon.com/INIU-Portable-External-Powerbank-Compatible/dp/B07H6LB4J4/) |

## Assembly Instructions

1. Print your desired Stand at 20% infill.
2. Orient your Nano vertically and snap your Jetson Nano into the front the Stand — you should hear a nice click sound.
3. If you're adding a Portable Battery, orient your battery horizontally and snap the battery into the back of the Stand — you should hear a nice click sound.

#### Printer Settings
Each of these parts were printed on a [Prusa i3 MK3S](https://www.prusa3d.com/original-prusa-i3-mk3/) printer using the MK3S_MK3_0.2_Fast profile (0.2mm layer height) with PLA. 

## Credits
1. The Clips for the Nano and Battery were derived from this [8020 Rail ATMega2560 Clip](https://www.thingiverse.com/thing:155130) by [the_digital_dentist](https://www.thingiverse.com/the_digital_dentist/about).

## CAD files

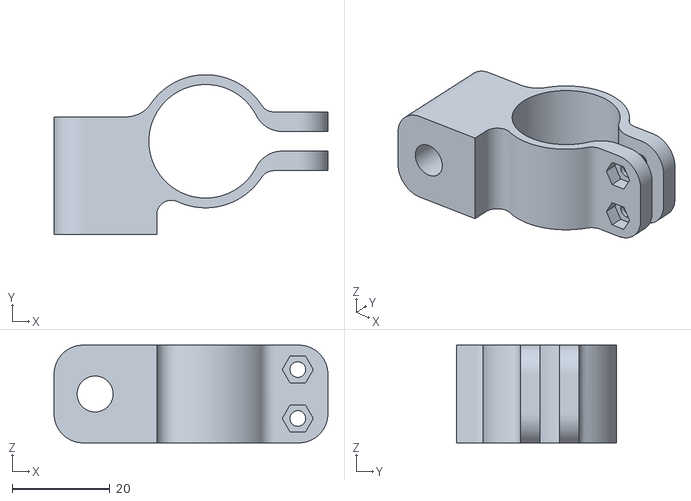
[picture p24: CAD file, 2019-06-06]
bicycle-mount/jetson_nano_clip_bicycle_sensor.stl
56.0 x 32.6 x 20.0

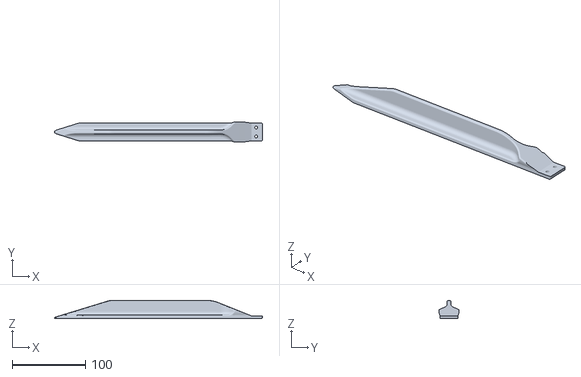
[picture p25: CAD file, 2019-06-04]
gardening/jetson_nano_outdoors_stake.stl
284.3 x 27.9 x 25.0

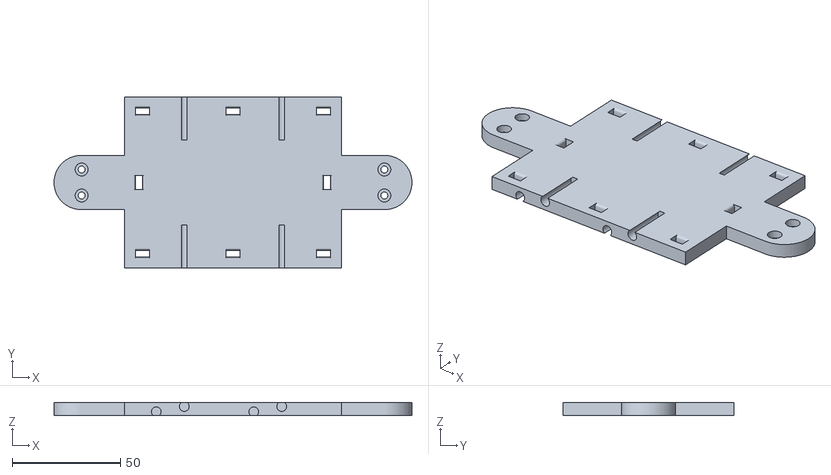
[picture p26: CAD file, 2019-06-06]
magnetic-mount/jetson_nano_board_magnet.stl
165.3 x 79.0 x 6.00

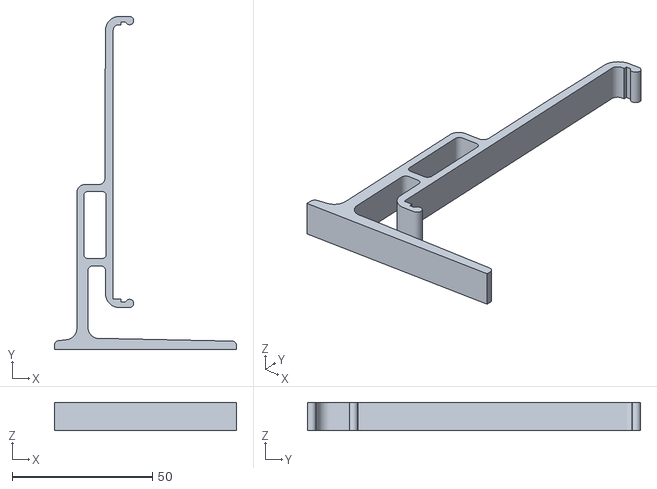
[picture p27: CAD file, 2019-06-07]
stands/jetson_nano_clip-feet.stl
65.0 x 119.0 x 10.0

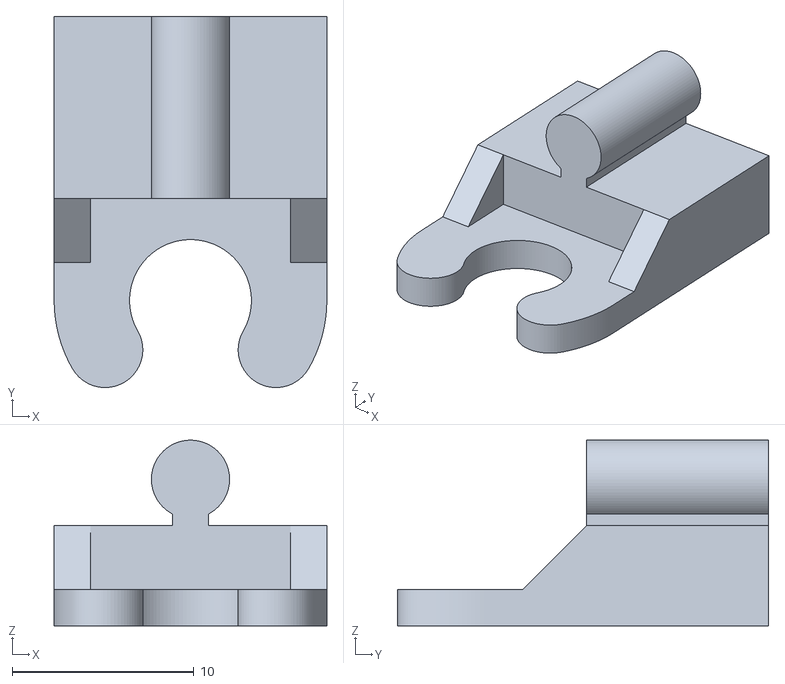
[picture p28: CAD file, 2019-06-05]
suction-cup-mount/jetson_nano_clip_suction-cup.stl
15.0 x 20.4 x 10.2

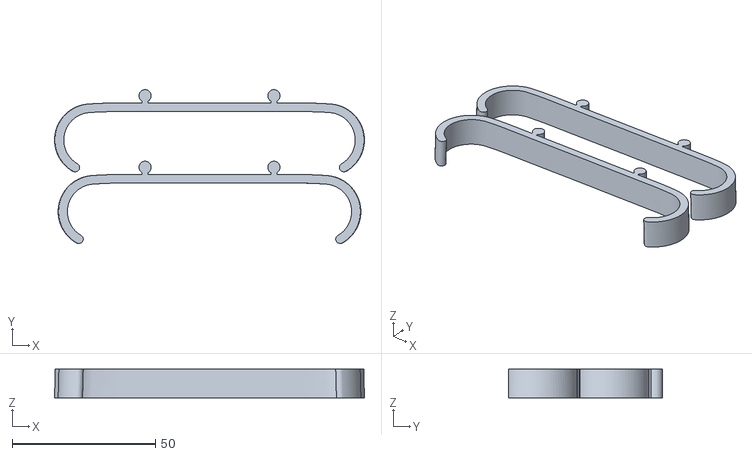
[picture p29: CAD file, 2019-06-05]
tripod-mount/jetson_nano_clips_tripod.stl
108.3 x 53.7 x 10.0

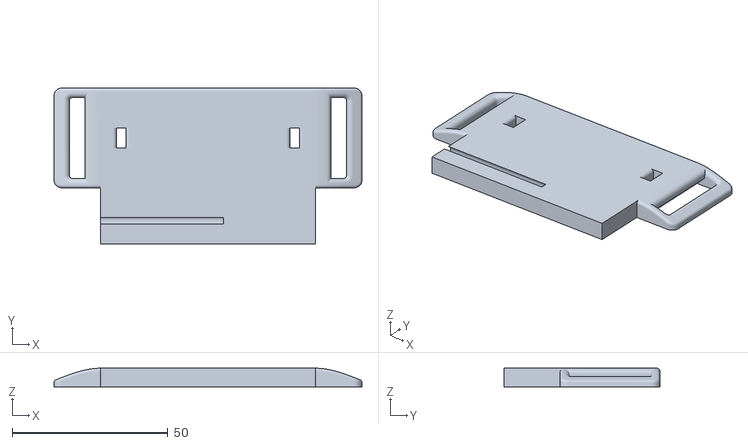
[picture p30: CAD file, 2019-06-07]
utility-belt/jetson_nano_battery_buckle.stl
98.8 x 50.0 x 6.00

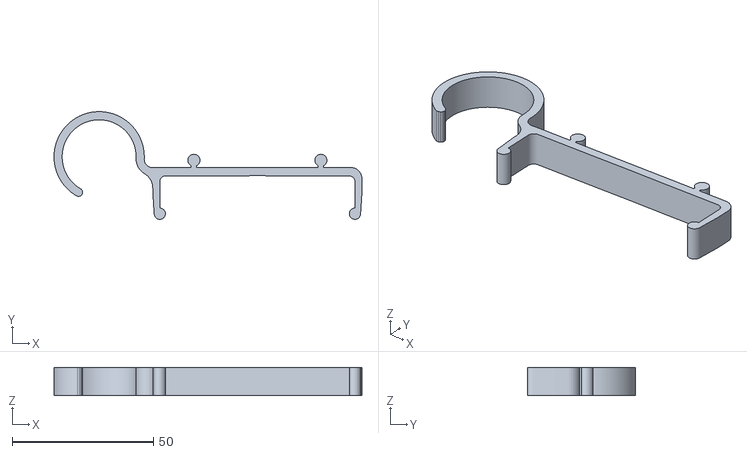
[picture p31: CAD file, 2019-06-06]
bicycle-mount/jetson_nano_clip_bicycle.stl
109.2 x 38.2 x 10.0

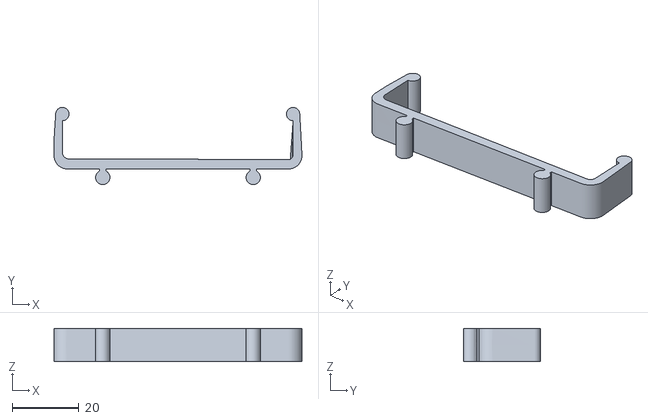
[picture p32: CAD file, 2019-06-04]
gardening/jetson_nano_clip_battery.stl
74.2 x 23.1 x 10.0

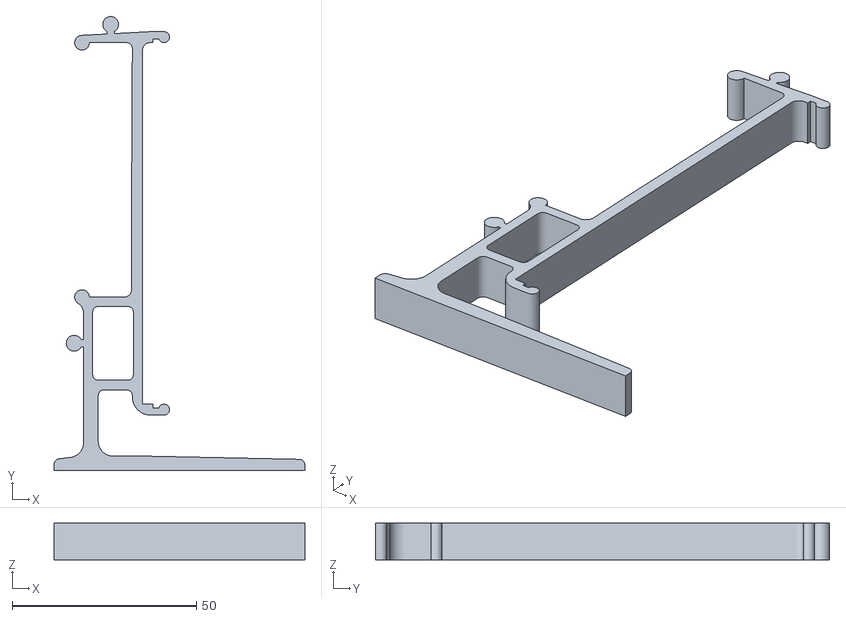
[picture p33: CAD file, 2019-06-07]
stands/jetson_nano_clip-feet-battery-rail.stl
68.0 x 123.1 x 10.0

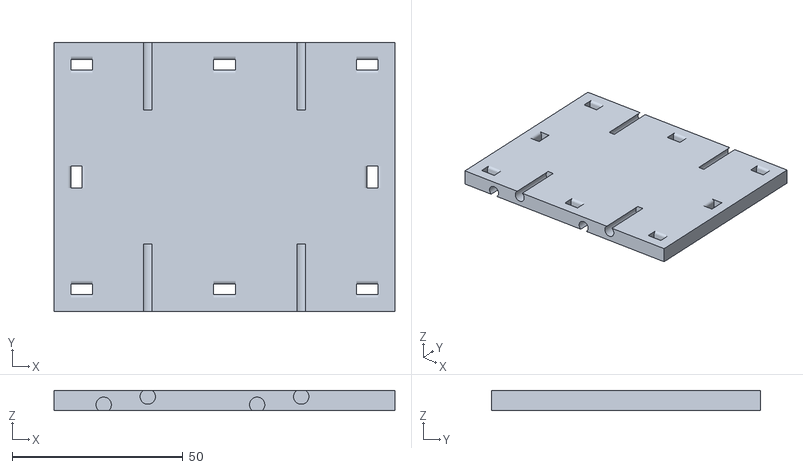
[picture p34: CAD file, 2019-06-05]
suction-cup-mount/jetson_nano_board.stl
100.0 x 79.0 x 6.00

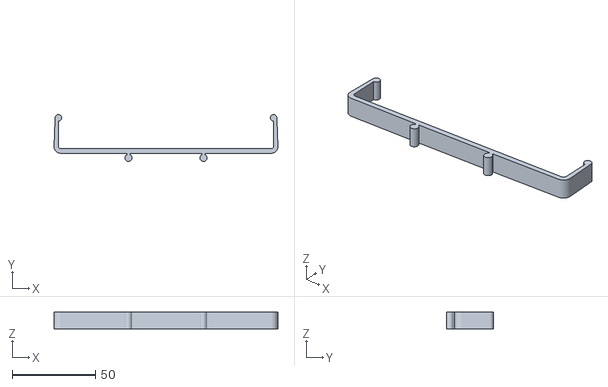
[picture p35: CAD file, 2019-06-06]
utility-belt/jetson_nano_clip_battery_vertical.stl
134.3 x 28.2 x 10.0

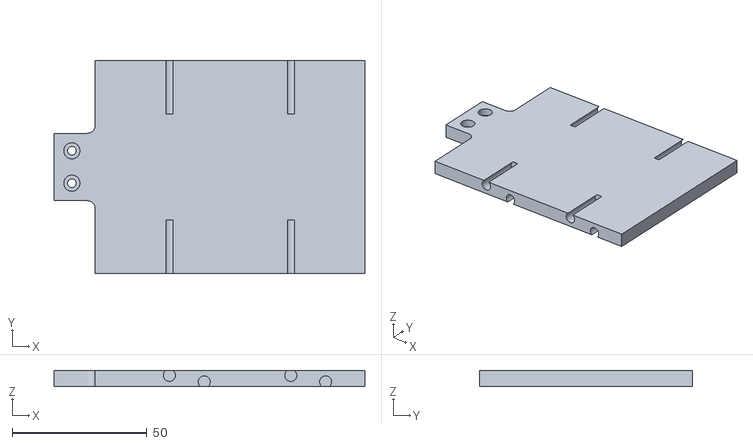
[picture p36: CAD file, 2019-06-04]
gardening/jetson_nano_outdoors_stake_board.stl
115.3 x 79.0 x 6.00

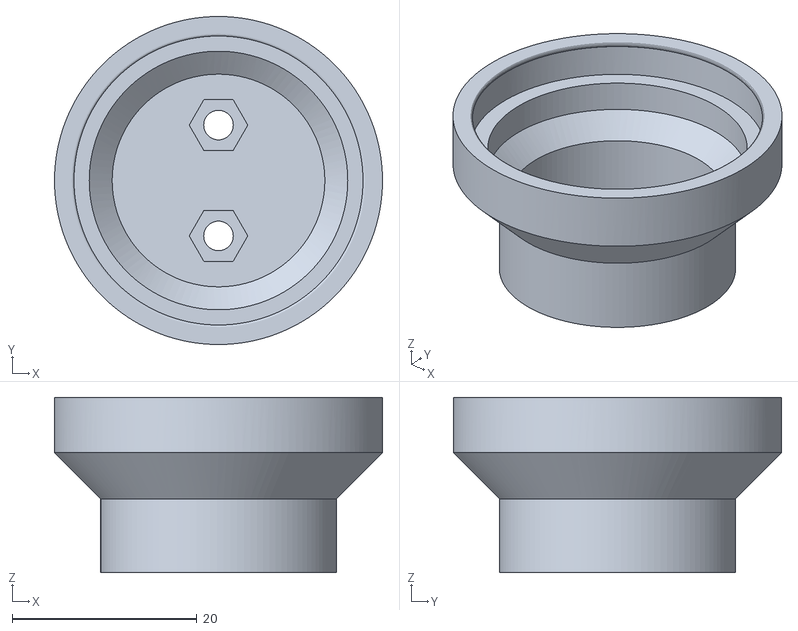
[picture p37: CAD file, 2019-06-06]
magnetic-mount/jetson_nano_clip_magnet.stl
35.5 x 35.5 x 19.0

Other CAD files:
magnetic-mount/jetson_nano_clip_battery.stl
stands/jetson_nano_clip-feet-battery.stl
utility-belt/jetson_nano_board_buckle.stl
gardening/jetson_nano_clip.stl

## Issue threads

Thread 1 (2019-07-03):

What model of battery?

leopd, 2019-07-03:
What make/model of battery are these designs sized for?

madelinegannon, 2019-07-03:
I'm using this INIU 5V/3A, 10,000mAh battery pack that's spec'ed in NVIDIA's Jetbot [BOM](https://github.com/NVIDIA-AI-IOT/jetbot/wiki/bill-of-materials)

leopd, 2019-07-08:
Thanks!

Closed 2019-07-08.

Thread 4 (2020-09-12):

Utility belt for Xavier NX

mpottinger, 2020-09-12:
Hello, just curious, would these designs work as well for the Xavier NX? It is the same form factor as the Jetson Nano, but more powerful. Specifically the Utility belt.

madelinegannon, 2020-09-14:
Basically, but there would need to be slight modifications ... the board for the Nano and Xavier NX are the same. However, the XNX sits in a plastic case that holds its wifi antennae. This clips would just need to be modified a bit to receive the XNX's thicker plastic case.

mpottinger, 2020-09-16:
Ok thank you. Yes powering even the nano has been a pain for me, the micro usb doesn't supply enough power for heavy usage.

madelinegannon, 2020-09-23:
If you find better battery options, please share them with us!

Closed 2020-09-23.

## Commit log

2019-06-04 added stls
    [jetson_nano_clip.stl, jetson_nano_clip_battery.stl, jetson_nano_outdoors_stake.stl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]
2019-06-04 fixed hole diameter
    [jetson_nano_outdoors_stake.stl]
2019-06-04 added utility belt files
    [jetson_nano_battery_buckle.stl, jetson_nano_board_buckle.stl, jetson_nano_clip.stl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]
2019-06-05 added tripod mount files and instructions
    [jetson_nano_board.stl, jetson_nano_clips_tripod.stl]
2019-06-05 added car mount
    [jetson_nano_board.stl, jetson_nano_clip.stl, jetson_nano_clip_suction-cup.stl]
2019-06-06 decreased length by 1mm
    [jetson_nano_clip_battery-vertical.stl, jetson_nano_clip_battery_vertical.stl]
2019-06-06 added bicycle assembly
    [jetson_nano_board.stl, jetson_nano_clip.stl, jetson_nano_clip_bicycle.stl]
2019-06-06 fixed naming error
    [jetson_nano_board.stl, jetson_nano_clip.stl, jetson_nano_clip_bicycle.stl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]
2019-06-06 rotated to correct Z up
    [jetson_nano_clip_bicycle_sensor.stl]
2019-06-06 restructured repo
    [jetson_nano_board.stl, jetson_nano_clip.stl, jetson_nano_clip_suction-cup.stl]
2019-06-06 added magnet assembly
    [jetson_nano_board_magnet.stl, jetson_nano_clip.stl, jetson_nano_clip_battery.stl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]
2019-06-07 added zip tie holes
    [jetson_nano_battery_buckle.stl]
2019-06-07 added stand clips
    [jetson_nano_clip-feet-battery-rail.stl, jetson_nano_clip-feet-battery.stl, jetson_nano_clip-feet.stl]
2019-06-07 added assets
    [jetson_nano_clip.stl]
2019-06-11 renamed folder
    [jetson_nano_clip.stl, jetson_nano_clip_battery.stl, jetson_nano_outdoors_stake.stl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]
2019-08-25 Fix mis-titled magnetic mount photos
